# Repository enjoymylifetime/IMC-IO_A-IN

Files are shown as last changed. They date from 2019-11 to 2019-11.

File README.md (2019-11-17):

#### 使用说明

	SCH文件夹为原理图；

	PCB文件夹为PCB；

	REF文件夹为开发设计的参考资料；

	MFG文件夹为生产制造文件；

	DXF文件夹为结构图；

	DOC文件夹为各类文档；

	PER文件夹为外围设备或模块；

	PRD文件夹为产品/项目需求；

	SRC文件夹为源代码

### 版本说明

#### A1版

##### 一、需要改进点：

		1、U26的VREF_DAC改成VREF_ADC；

		2、R217、R231、R245、R259的VDD_5V_MAIN改成VREF_ADC；

		3、R212、R222、R226、R236、R240、R250、R254、R264改成51K；

		4、R215和R216等改成0欧；

		5、R217等改成1K；

		6、R218、R220、R221等改成1.5K；

		7、FB1去掉，U25焊上REF3025AIDBZR； 

		8、U25改用3.3V供电；

		9、D21 pin1的GND改成；

		10、R162和R168由原来的887R改成1.1K，15V改成12V电源

		11、由于FPGA 5M240ZT100资源不够，所以改用5M570ZT100，但有部分脚不兼容：

			1）39pin由原来的F_EX_DATA5改接到1.8V，26pin由原来的NC接到F_EX_DATA5；

			2）88pin EX_RD 	--> 1.8V, 98pin NC	-->EX_RD;

			3)8pin NC 	-->GND;

			4)1pin	GNG	-->NC;

			5)90pin EX_ADD0	-->GND, 99pin NC	-->EX_ADD0;

			6)95pin EX_ADD3	-->GND, 100pin NC	-->EX_ADD3;

			7）37pin  F_EX_DATA2 -->,   27pin NC -->F_EX_DATA2 ;

#### A2版

	1、修复了A1的改进点；

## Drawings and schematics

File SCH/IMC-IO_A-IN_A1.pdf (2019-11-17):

D | D

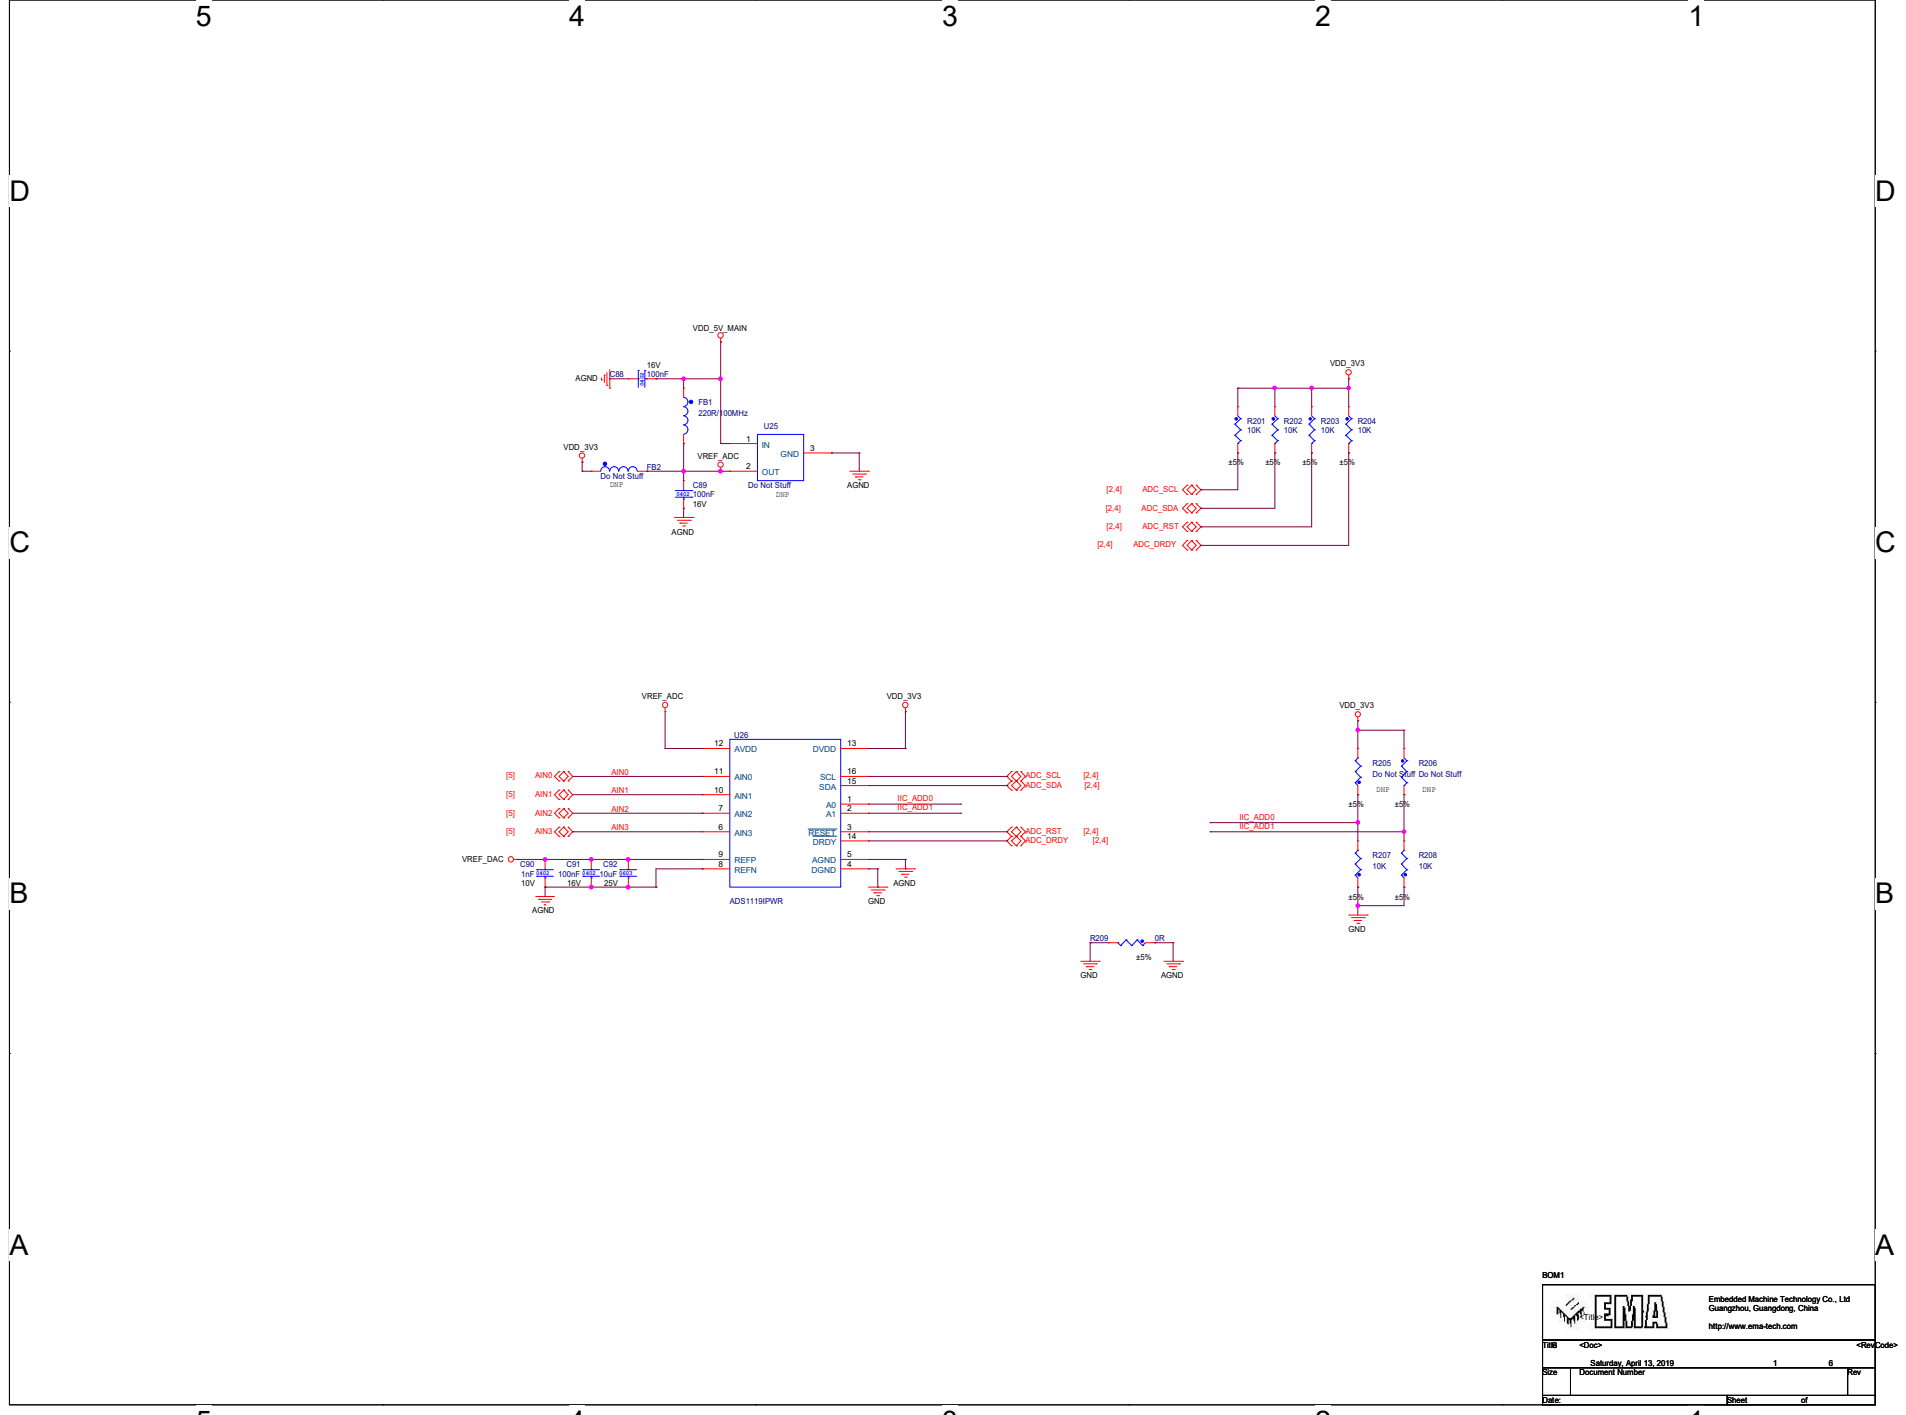
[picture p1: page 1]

Embedded Machine Technology Co., Ltd
Guangzhou, Guangdong, China

http://www.ema-tech.com

55

44

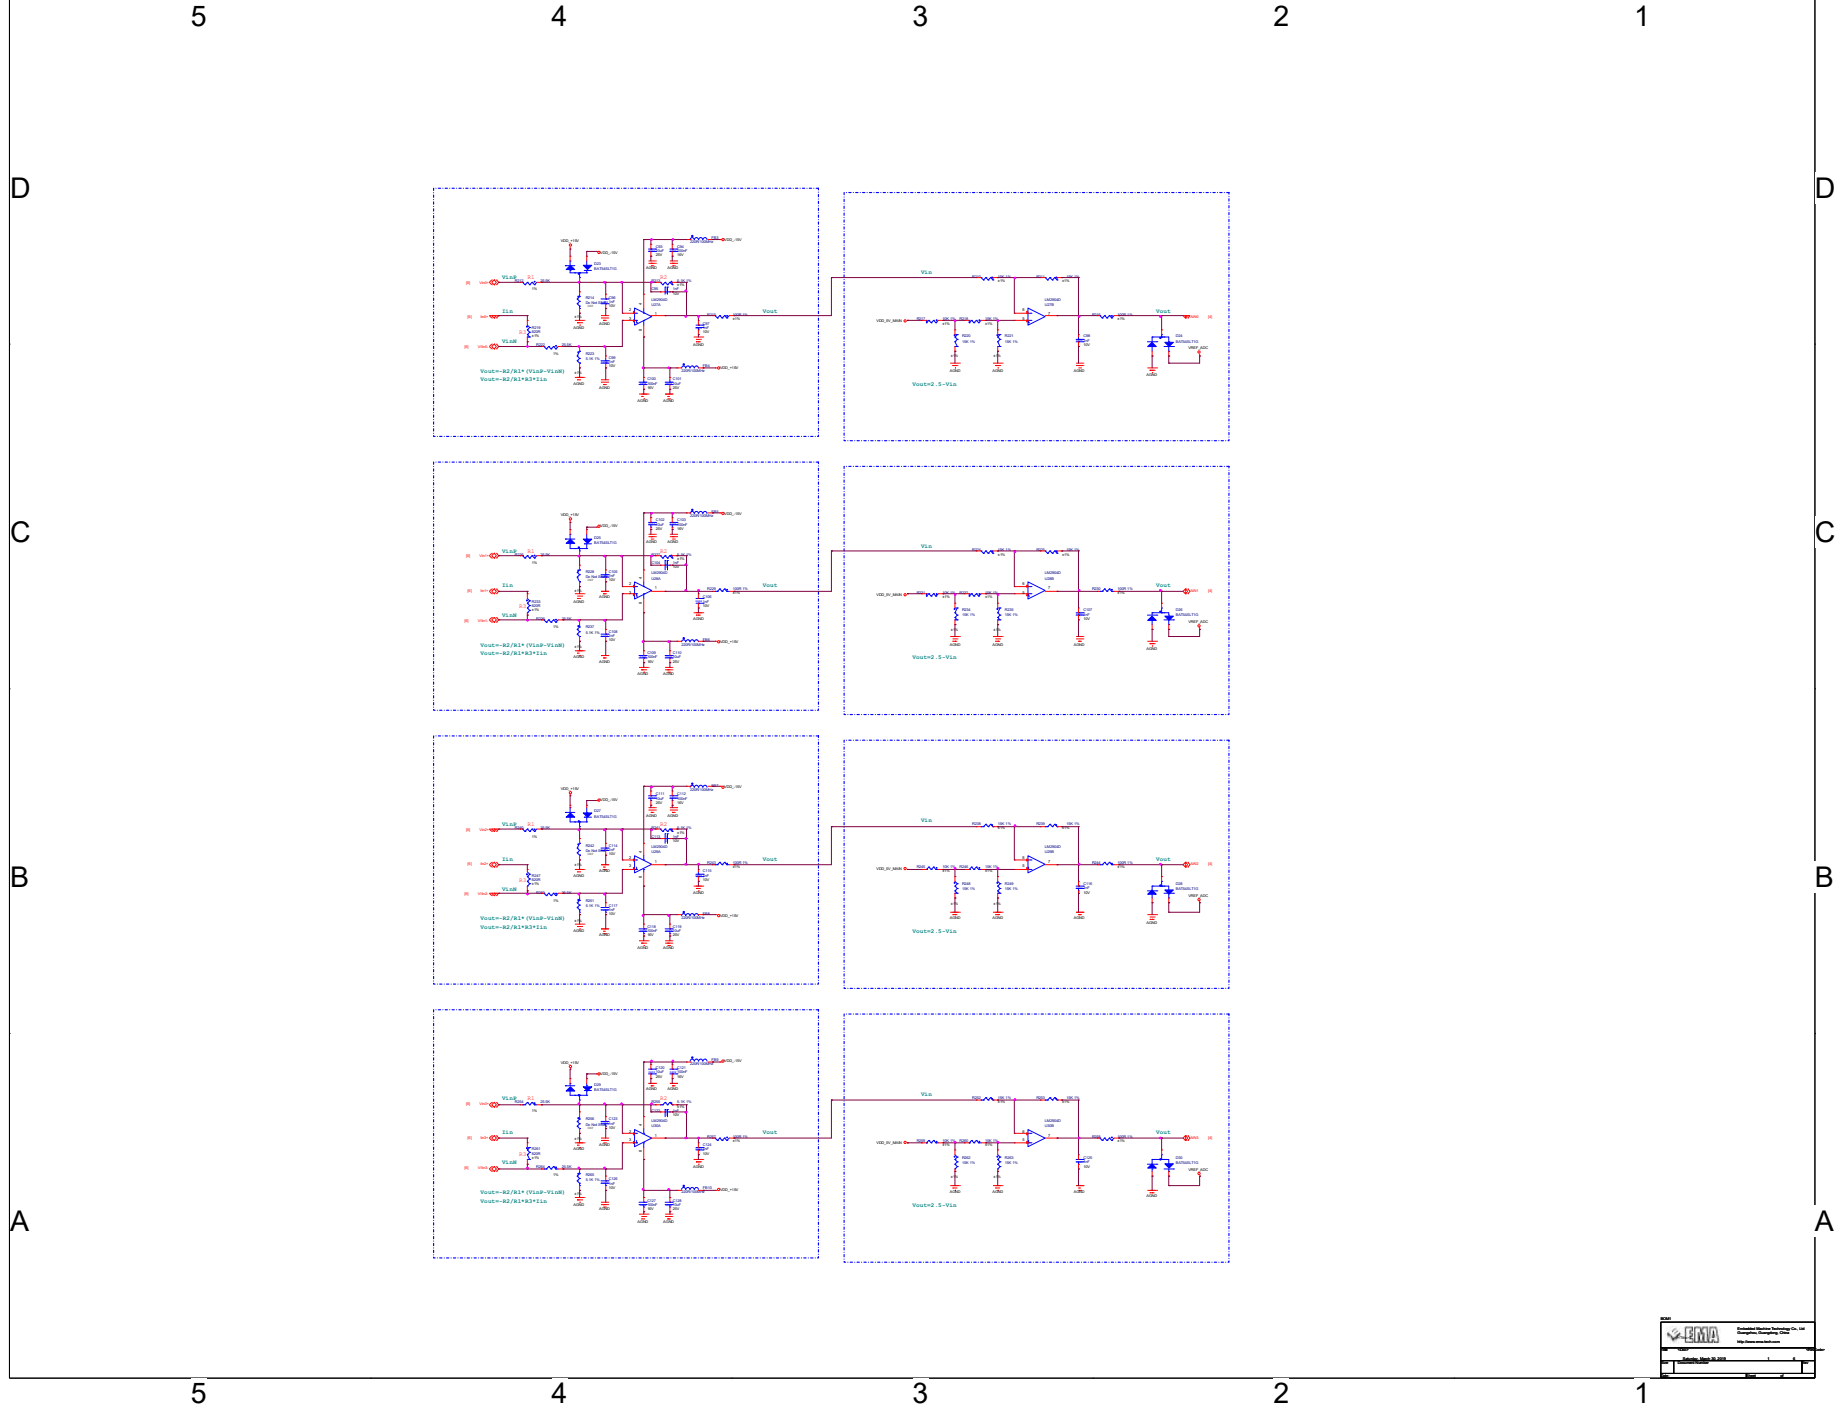
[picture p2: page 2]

D | D

R1

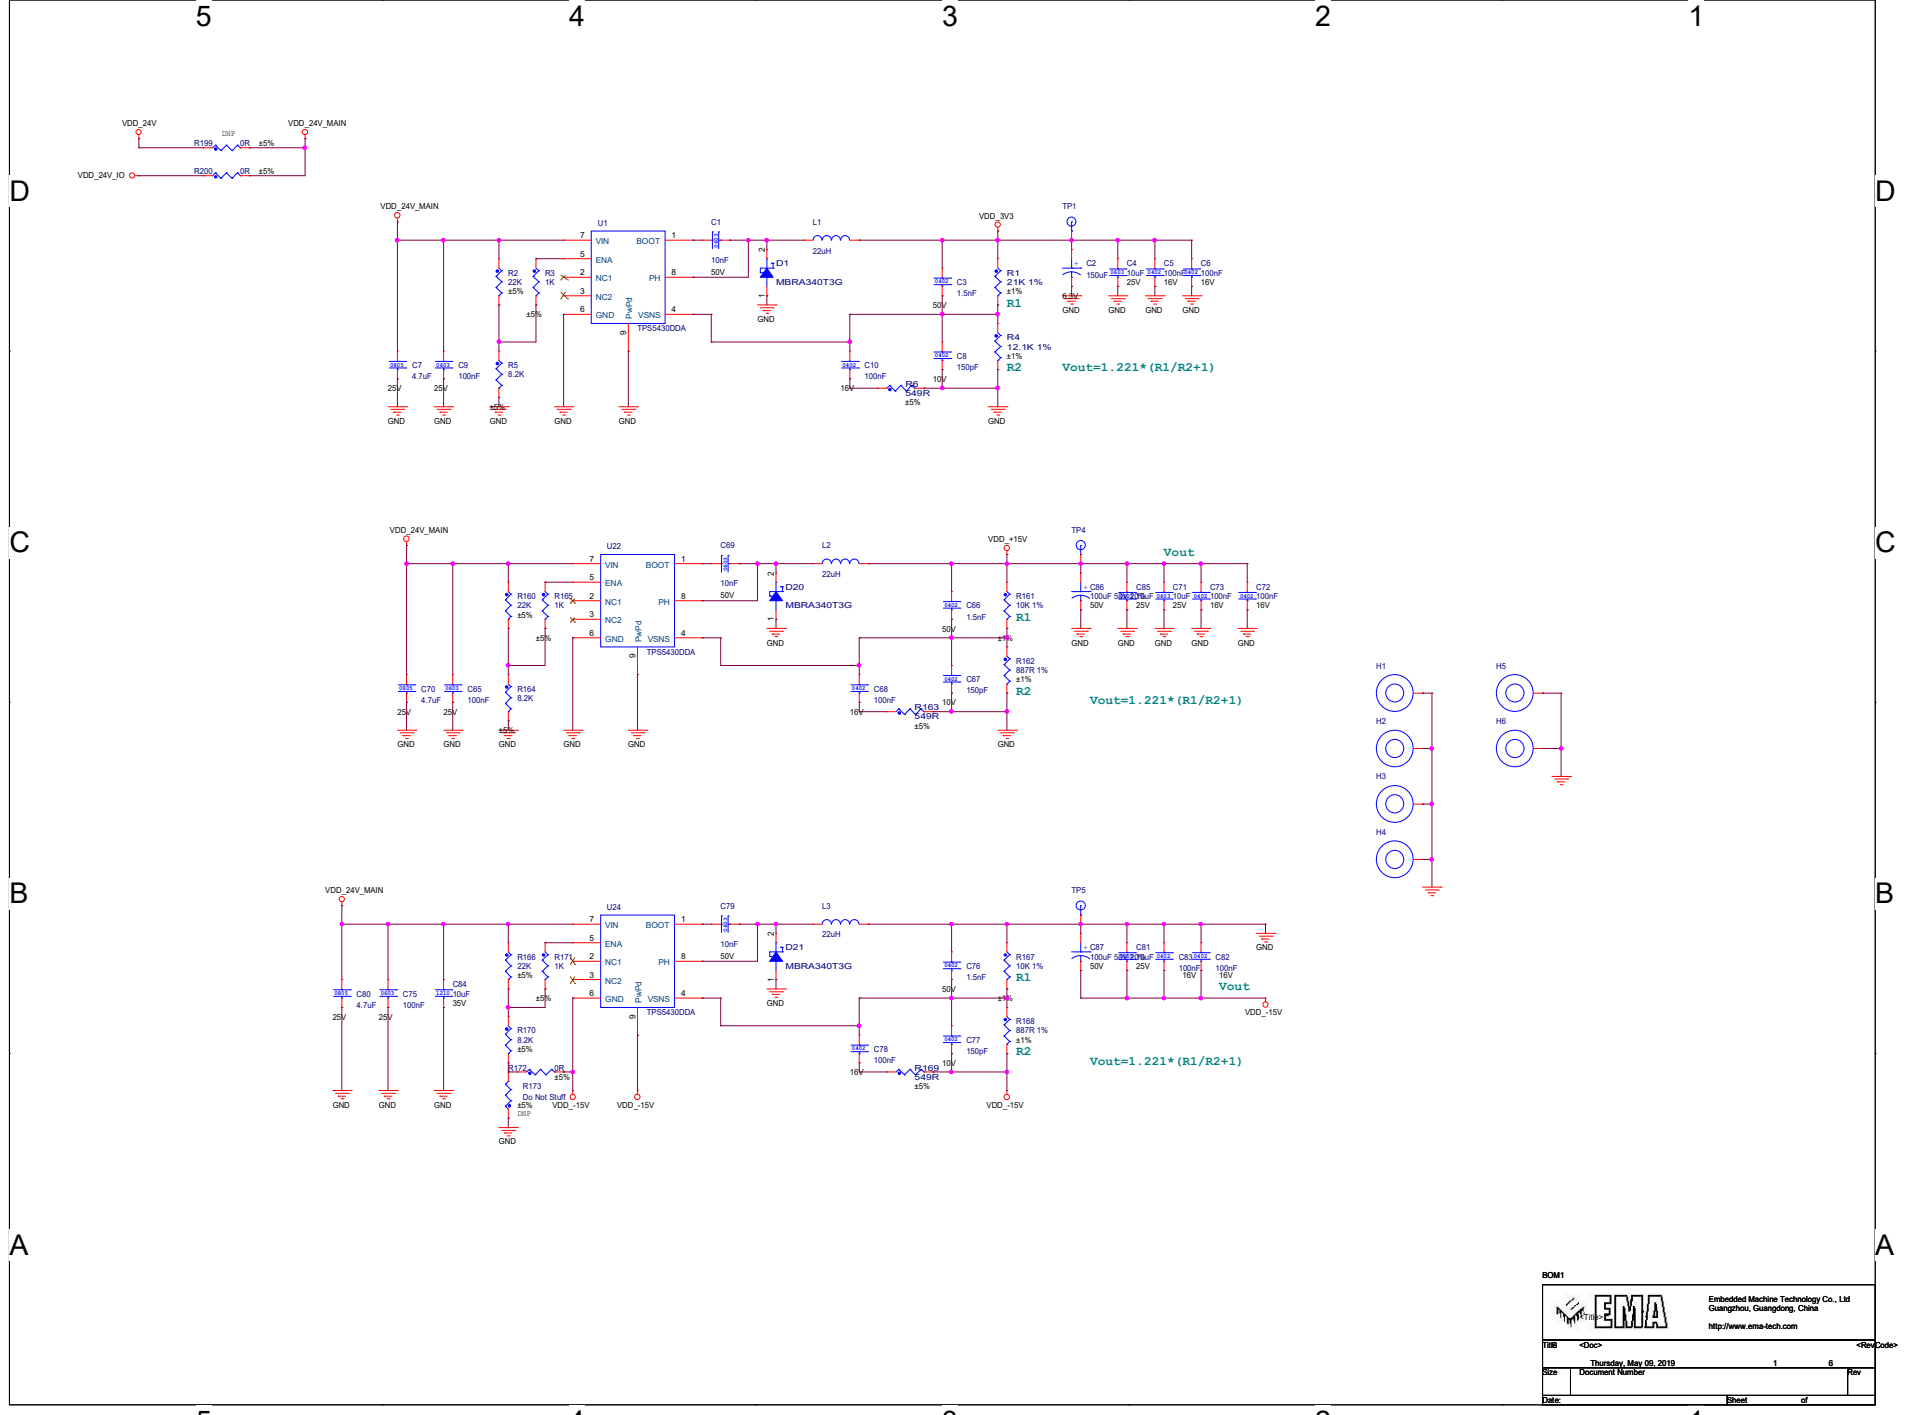
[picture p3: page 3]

D | D

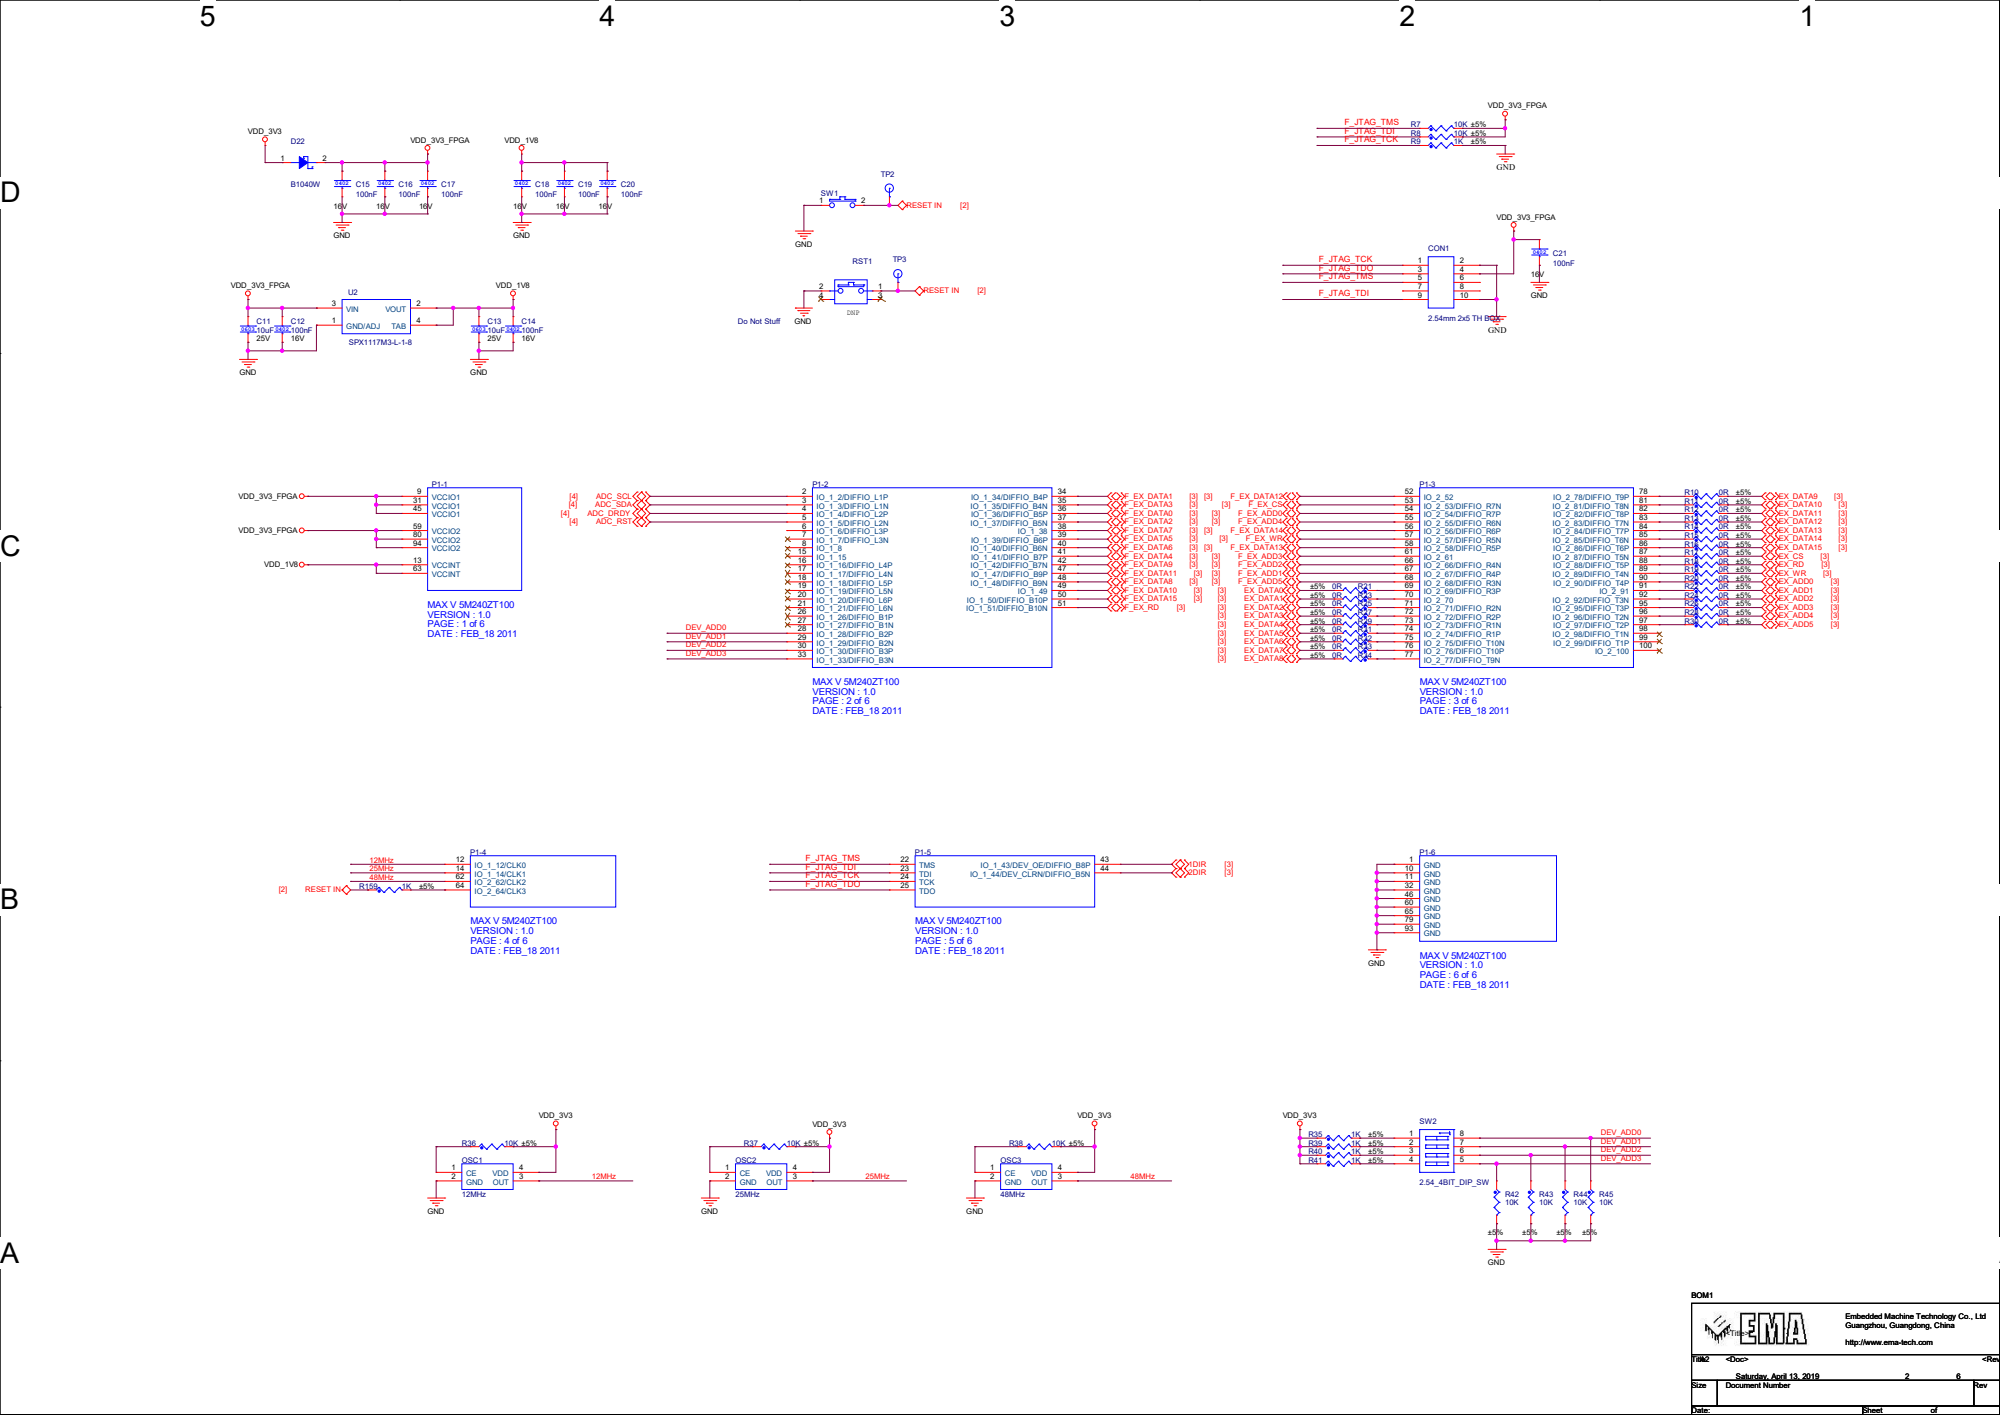
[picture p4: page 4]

D | D

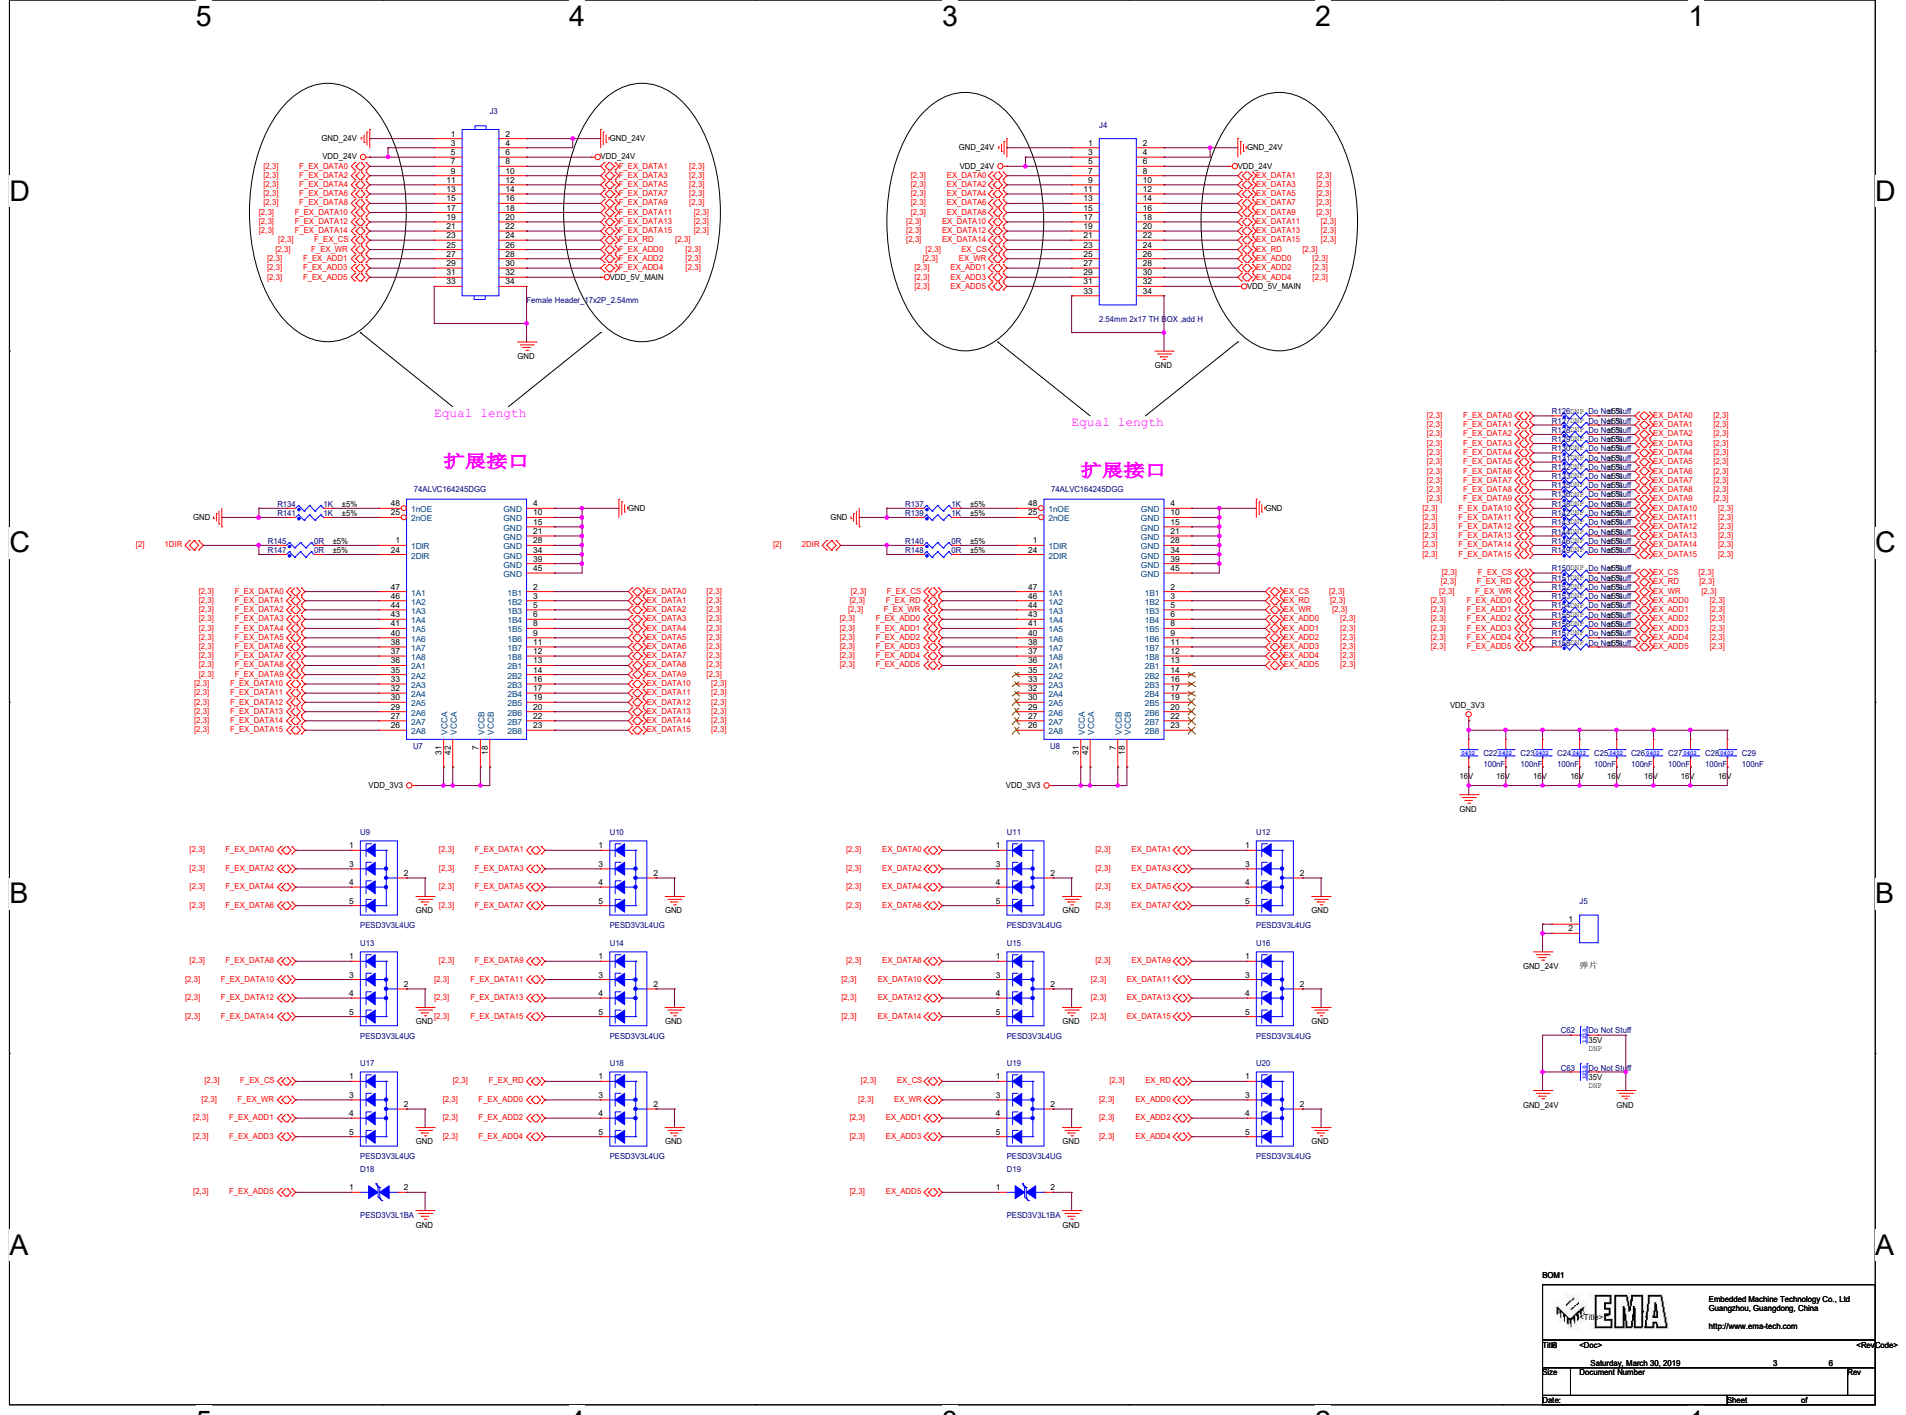
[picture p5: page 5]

D | D

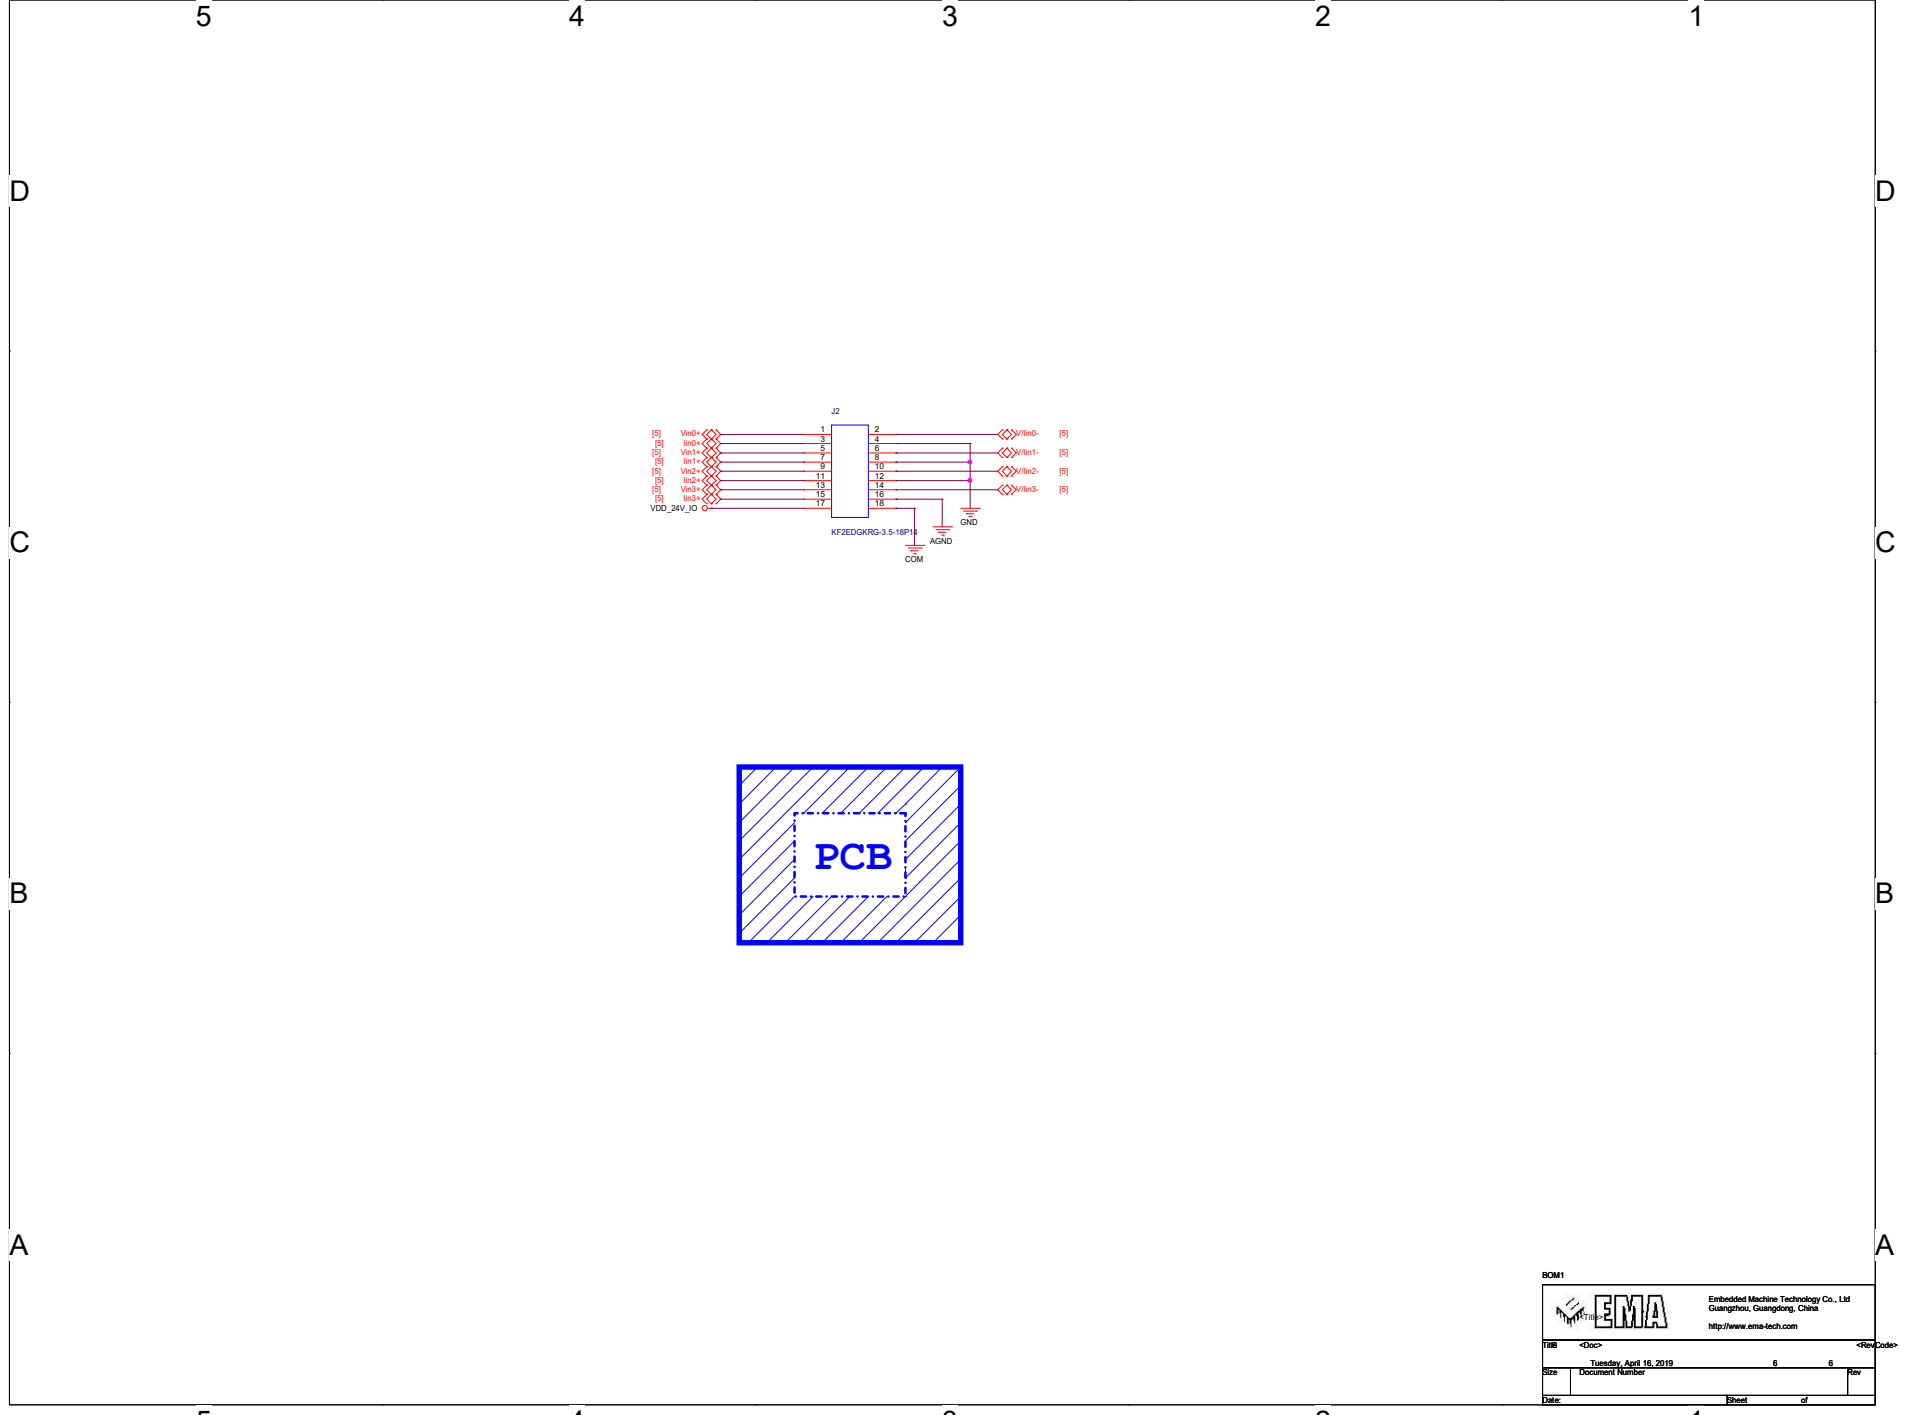
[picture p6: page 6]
GND; AGND; VDD_24V_IO; COM; [5] Iin0+; Vin0+; V/Iin0-; [5] Iin1+; [5] Vin1+; [5] Iin2+; [5] Vin2+; [5] Iin3+; [5] Vin3+; V/Iin1-; V/Iin2-; V/Iin3-; Tuesday, April 16, 2019; BOM1; PCB; KF2EDGKRG-3.5-18P14

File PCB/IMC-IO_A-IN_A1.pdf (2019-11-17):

## ART FILM - adt

A

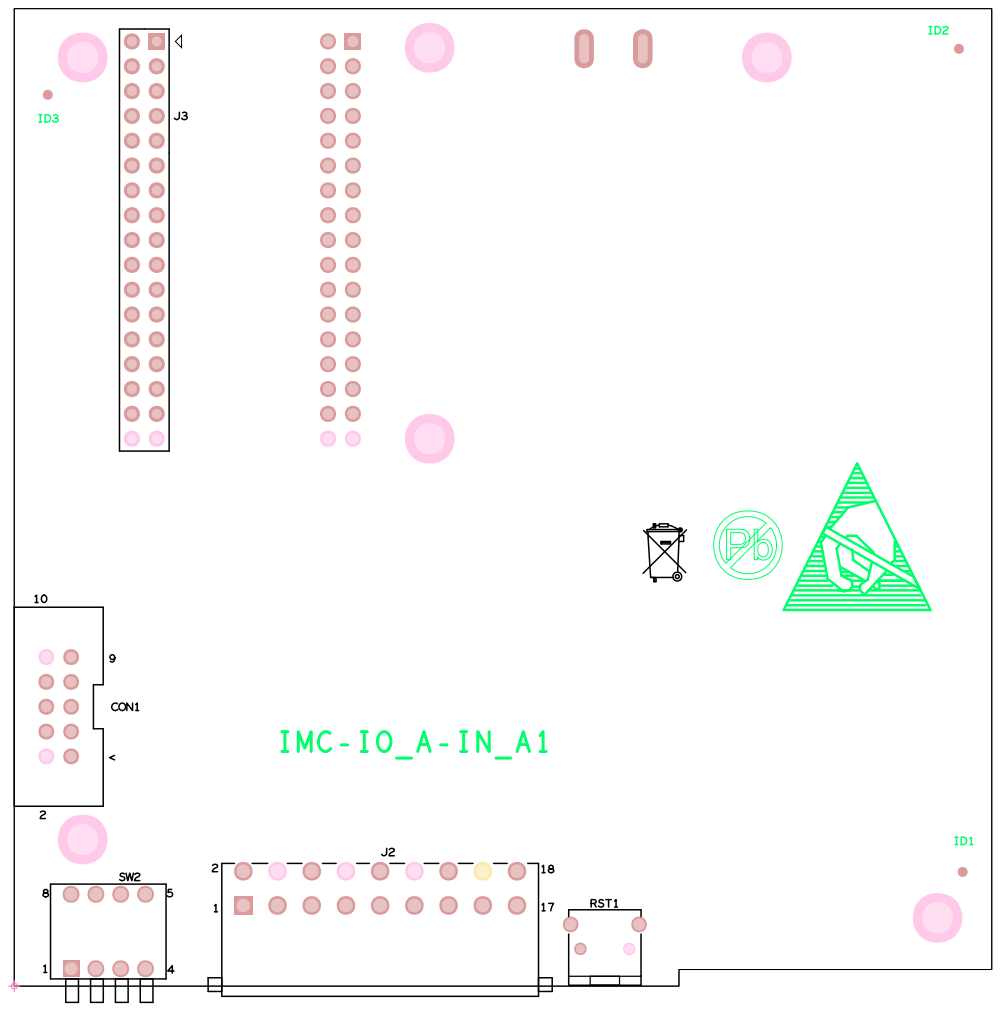
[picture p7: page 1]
RST1; IMC-IO_A-IN_A1; CON1

REVISIONS

REV | ACTION | DESIGNER | DATE | QA

XXXXXX | XX | INITIAL RELEASE | XXXX | XXXX-XX-XX | XXXX

XXXXXX | XX | UPDATE | XXXX | XXXX-XX-XX | XXXX

ART FILM - adt

## ART FILM - adb

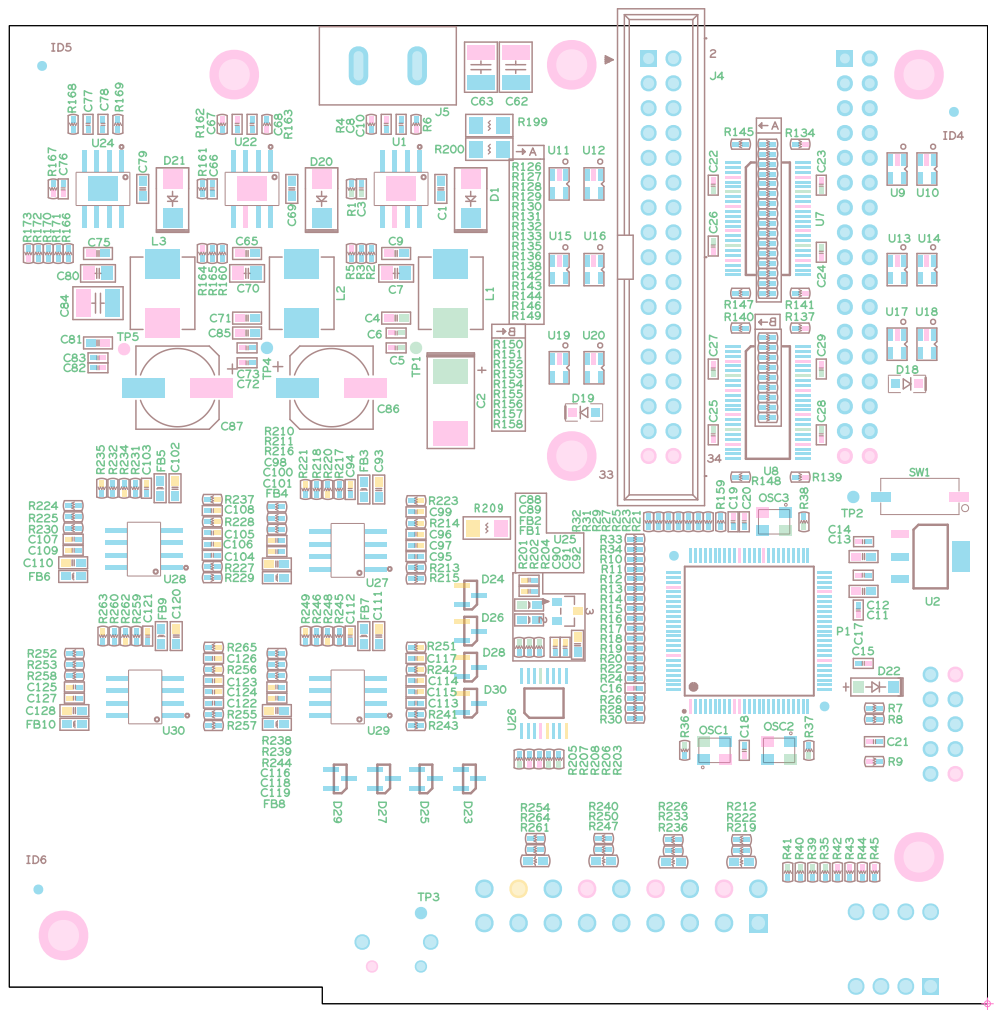
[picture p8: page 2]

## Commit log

2019-02-28 初次提交
    [IMC-IO_A-IN_A1.DSN]
2019-03-30 提交文件
    [IMC-IO_A-IN_A1.DSN]
2019-04-09 完成布局
    [IMC-IO_A-IN_A1.DSN]
2019-04-13 完成导出gerber
2019-04-16 出BOM
    [IMC-IO_A-IN_A1.DSN]
2019-04-29 完整提交
    [AD.SchDoc, IMC-IO_A-IN_A1.csv, IMC-IO_A-IN_A1.xlsx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]
2019-05-28 提交更新SCH PDF
2019-06-21 初始提交A2原理图
    [IMC-IO_A-IN_A2.DSN, art_param.txt]
2019-06-21 扩展接口不用buffer芯片改用电阻
    [IMC-IO_A-IN_A2.DSN]
2019-06-23 提交IMC-IO_A-IN A2 PCB
2019-07-04 提交PCB SCH
    [IMC-IO_A-IN_A2.DSN]
2019-07-04 提交reademe
2019-07-04 提交gitignore
2019-07-05 PCB更改了铜皮跟通孔的连接方式
2019-07-19 jtag增加了33欧电阻，D22改成磁珠
    [IMC-IO_A-IN_A2.DSN]
2019-07-29 PCB FPGA更改
2019-07-29 SCH FPGA更改
    [IMC-IO_A-IN_A2.DSN]
2019-08-27 提交A1
    [AD.SchDoc, IMC-IO_A-IN_A1.DSN, IMC-IO_A-IN_A1.csv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]
2019-11-17 提交FGPA源码
